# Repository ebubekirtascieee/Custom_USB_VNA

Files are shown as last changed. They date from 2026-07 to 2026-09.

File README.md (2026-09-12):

# Custom_USB_VNA
Single-port VNA (Vector Network Analyzer) operating in the 400 MHz – 3.0 GHz range, featuring a custom-designed 4-layer PCB based on the Raspberry Pi Pico 2 MCU and a USB interface.
Superior performance for 430 MHz (ISM), 900 MHz (ISM), 1090 MHz (ADS-B), 1.5 GHz (GPS), and 2.4 GHz (Wi-Fi/Bluetooth) metrology with minimal cost!



Pico_Top

Various types of charts support, including 1001 points Smith chart, via a Python-based (PyQt6) custom graphical user interface (GUI).

Test_GUI_2

Time Domain Reflectometry (TDR) for distance-to-fault calculations and automated cable loss measurements.

Cable_Loss

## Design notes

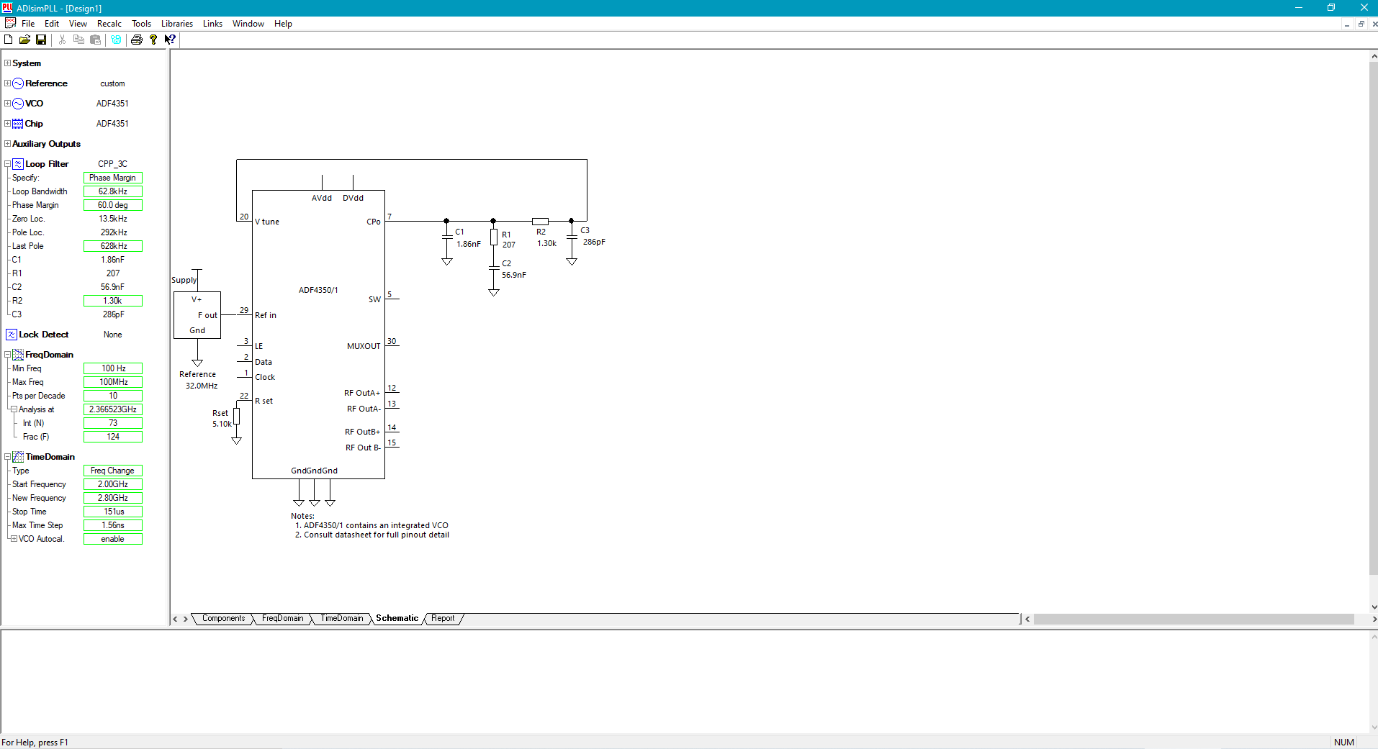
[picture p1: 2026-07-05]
Hardware/Loop_Filter.png

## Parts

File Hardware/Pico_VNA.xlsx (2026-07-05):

Comment | Description | Designator | Footprint | LibRef | Quantity
100nF 0603 | CAP 100nF 25V ±20% 0603 (1608 Metric) Thickness 1mm SMD | C1, C12, C13, C18, C21, C23, C24, C29, C30, C31, C35, C36, C41, C44, C51, C53, C56, C59, C61, C62, C75, C77, C79, C80, C81 | CAPC0603(1608)100_N | CMP-1035-02589-1 | 25
2.2uF 0805 | CAP CER 2.2UF 16V X7R 0805 | C2, C8, C10, C73 | FP-C0805C225K4RACAUTO-MFG | CMP-2007-03267-2 | 4
1uF 0805 |  | C3, C9, C11, C52, C57, C58, C74 | CAPC2013X145X50NL20T25 | CMP-2007-01121-1 | 7
0805 10nF |  | C4, C19 | CAPC2013X94X50ML20T25 | CMP-2007-04453-1 | 2
10uF 1206 | 10uF 16V ±10% 3Ω 1206 SMD Tantalum Capacitor TAJA106K016RNJ | C5, C6 | FP-TAJA-MFG | CMP-1661-00004-2 | 2
10nF 0603 | CAP 10nF 25V ±20% 0603 (1608 Metric) Thickness 1mm SMD | C7 | CAPC0603(1608)100_N | CMP-1035-02589-1 | 1
100pF 0603 |  | C14, C15, C20, C28, C40, C42, C43, C45, C48, C49, C55, C71, C72, C82, C83, C84 | CAPC1608X92X38LL15T08 | CMP-2006-01182-1 | 16
1.8nF 0603 | CAP CER 1800PF 25V X7R 0603 | C16, C32, C68, C70 | FP-C0603C-CF-MFG | CMP-03020-009150-1 | 4
270pF 0603 |  | C17, C33 | CAPC1608X92X38LL15T08 | CMP-2006-01334-1 | 2
10uF 1206 | CAP 10uF 16V ±5% 1206 (3216 Metric) Thickness 1.9mm SMD | C22, C25, C34, C37, C50, C54, C60, C63, C64, C65, C66, C67, C69 | CAPC1206(3216)190_M | CMP-1037-04973-1 | 13
100nF 0603 | CAP 100nF 16V ±0.1pF 0603 (1608 Metric) Thickness 1mm SMD | C26, C27, C38, C39, C76, C78 | CAPC0603(1608)100_L | CMP-1035-00228-1 | 6
56nF 0603 |  | C46, C47 | CAPC1608X90X35LL15T15 | CMP-2006-04522-1 | 2
PA2748NL | CHOKE COMMON MODE 1125UH 1.8A SMD | CMC1 | DFN838P1270X560-4N | PA2748NL | 1
PESD5V0S1BA,115 | TVS DIODE 5V 14V SOD323 | D2 | FP-SOD323-CA-MFG | CMP-14432-000001-1 | 1
150120VS75000 | Led, Green, 570 Nm, 2 V, 30 Ma, 40 Mcd Rohs Compliant: Yes | DS1 | WL-SMCW_1206_150120xx75000 | CMP-1426-00016-4 | 1
LCB3216-102Y-N | Chip Ferrite Bead, 1206, 1kΩ @ 100MHz, max. 0.200Ω, 25%, 2A | FB1, FB2, FB3, FB4, FB5, FB8 | FP-BLM31-0_2-t1_6-IPC_C | CMP-06046-002145-1 | 6
BLM18HE152SN1D | Chip Ferrite Bead, 0603, 1500Ω @ 100MHz, 0.5Ω, 25%, 500mA | FB6, FB7 | FP-BLM18-0_15-t0_8-IPC_C | CMP-0686-00368-3 | 2
BMI-S-205-F | RF Shield Frame 1.000 _25.40mm_ X 1.500 _38.10mm_ Solder | H1, H2, H3 | LAIRD_BMI-S-205-F | CMP-058-000000-1 | 3
32K201-400L5 | CONN SMA JACK R/A 50OHM PCB | J1 | FP-32K201-400L5-MFG | CMP-0751-00005-2 | 1
USB4125-GF-A_REVA2 |  | J2 | GCT_USB4125-GF-A_REVA2 | CMP-039-000000-1 | 1
5-146256-2 | CONN HEADER VERT 4POS 2.54MM | J3 | FP-5-146256-2-MFG | CMP-03369-000128-1 | 1
U.FL-R-SMT-1(80) | CONN U.FL RCPT STR 50 OHM SMD | J4, J5 | FP-U_FL-R-SMT-1_80-MFG | CMP-11598-000004-1 | 2
5.6nH 0603 |  | L1, L2, L3, L4 | FP-AISC-0603HP-MFG | CMP-27750-000002-1 | 4
18nH 0805 | 18 nH Unshielded Drum Core, Wirewound Inductor 800 mA 130mOhm 0805 (2012 Metric) 0805CT-180EGTS | L5, L6, L7 | FP-LQW2BAN_00-MFG | CMP-06042-010439-1 | 3
5.1k 0603 | RES SMD 100 OHM 1% 1/8W 0603 | R1, R2 | FP-MCT0603-IPC_B | CMP-02407-010205-1 | 2
1Meg 0603 | RES SMD 1 MEGA OHM 1% 1/8W 0603 | R3 | FP-MCT0603-IPC_B | CMP-02407-010205-1 | 1
33R 0603 | RES 33 OHM 1% 1/4W 0603 | R4, R15 | FP-SR0603-MFG | CMP-03412-011068-1 | 2
4.7k 0603 | RES SMD 4.7kΩ 0.1% 1/16W 0603 | R5, R14, R42, R43, R46, R47 | FP-CPF0603-MFG | CMP-03211-011109-1 | 6
33R 0603 | RES SMD 33Ω 0.1% 1/16W 0603 | R6, R8, R10, R19, R32, R33, R54, R55, R57, R58, R59, R60, R61, R62, R63, R65, R66, R67, R68, R69, R70, R71, R73, R74 | FP-CPF0603-MFG | CMP-03211-006902-1 | 24
49.9R 0603 | RES SMD 49.9 OHM 1% 1/10W 0603 | R7, R12, R30, R31, R35, R37 | FP-RT0603-MFG | CMP-03412-022019-1 | 6
210R 0603 | RES 210Ω 1.00% 0.1W 0603 | R11, R18, R36 | FP-AC0603-IPC_B | CMP-03412-003885-2 | 3
0R 0603 | RES 0 OHM JUMPER 1/4W 0603 | R20, R24, R38 | FP-HCJ0603-MFG | CMP-26527-000122-1 | 3
16.5R 0603 | RES SMD 16.5 OHM 1% 1/10W 0603 | R21, R22, R23 | FP-RT0603-MFG | CMP-03412-005655-1 | 3
37.4R 0603 | RES SMD 37.4 OHM 0.1% 1/10W 0603 | R25 | FP-RT0603-MFG | CMP-03412-012358-1 | 1
150R 0603 | RES 150 OHM 1/10W .1% SMD 0603 | R26, R27 | FP-RT0603-MFG | CMP-2000-04520-2 | 2
1.3k 0603 | RES Thin Film, 1.3kΩ, 0.1%, 0.1W, 25ppm/°C, 0603 | R28, R29 | FP-TFCR0603-IPC_B | CMP-250906-187165-1 | 2
10k 0603 | RES SMD 10K OHM 0.05% 1/10W 0603 | R34, R39 | FP-RT0603-MFG | CMP-03412-024743-1 | 2
100k 0603 | RT0603 100KΩ 0.1W 50 ppm/°C 1.00% | R40, R41 | FP-RT0603-MFG | CMP-03412-006967-1 | 2
1k 0603 | RES Thin Film, 1kΩ, 0.1%, 0.1W, 25ppm/°C, 0603 | R44, R45, R48, R49, R52, R53 | FP-TFCR0603-MFG | CMP-250906-149963-1 | 6
100R 0603 | RES SMD 100 OHM 1% 1/8W 0603 | R50, R51 | FP-MCT0603-MFG | CMP-02407-008087-1 | 2
HHM22137A2 | RF Directional Coupler General Purpose 0603 (1608 Metric), 6 PC Pad | T1, T2 | HHM22137A2 | CMP-012-00000-1 | 2
RASPBERRY_PI_PICO_2 | Raspberry Pi Board, Arm Cortex-M0+; Core Architecture:Arm; Core Sub-Architecture:Cortex-M0+; Kit Contents:Raspberry Pi Pico Board; No. Of Bits:32Bit; Silicon Core Number:Rp2040; Silicon Manufacturer:Raspberry Pi | U1 | RASPBERRY_PI_PICO | CMP-007-000000-1 | 1
TPS7A2033PDBVR | IC REG LINEAR 3.3V 300MA SOT23-5 | U2, U3, U4, U16 | FP-DBV0005A-MFG | CMP-04917-000300-1 | 4
ADF4351BCPZ | Wideband Synthesizer with Integrated VCO, CP-32-2, Pb-Free, 490 Tray | U5, U6 | ADI-CP-32-2_N | CMP-0287-00014-1 | 2
GVA-62+ | No Description Available | U7, U8, U15 | DF782_MNC | GVA-63+ | 3
SYM-63LH+ | RF Mixer IC Cellular, GPS, ISM, PCS, WCDMA 1MHz ~ 6GHz | U9, U10 | FP-SYM-30DMHW+-MFG | CMP-199893-000002-1 | 2
PCM1808PWR | 24-bit, 99-dB SNR, 96-kHz stereo ADC with single-ended inputs | U11 | SOP65P640X120-14N | CMP-052-000000-1 | 1
TPS7A2045PDBVR |  | U12 | SOT95P280X145-5N | CMP-056-000000-1 | 1
OPA2365AIDR | IC OPAMP GP 2 CIRCUIT 8SOIC | U13, U14 | FP-D0008A-MFG | CMP-0272-00746-4 | 2
SI8641BB-B-IS1 | General Purpose Digital Isolator 2500Vrms 4 Channel 150Mbps 35kV/Âµs CMTI 16-SOIC (0.154, 3.90mm Width) | U17, U18, U19 | SOIC127P600X265-16N | CMP-060-000000-1 | 3
ECS-TXO-3225MV-320-TR | TCXO Oscillators 32.000 MHZ Multi-Volt +1.7 3.6V HCMOS TCXO +/-2.5 ppm -30 +85 C 3.2x 2.5mm RoHS | Y1 | OSC_ECS-TXO-3225MV-320-TR | CMP-041-000000-1 | 1

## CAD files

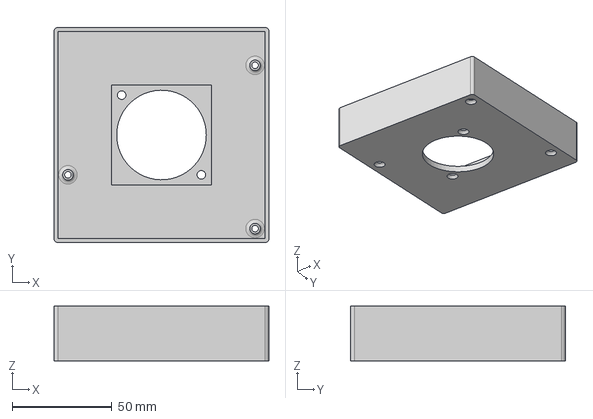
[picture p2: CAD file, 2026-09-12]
Mechanic/VNA_Box_Bottom.step
108.0 x 108.0 x 27.6 mm

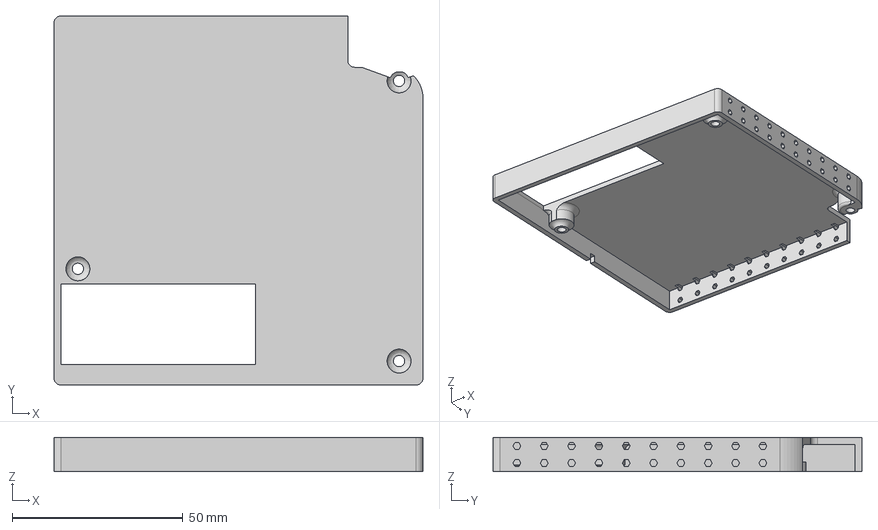
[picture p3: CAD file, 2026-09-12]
Mechanic/VNA_Box_Top.step
108.0 x 108.0 x 10.0 mm

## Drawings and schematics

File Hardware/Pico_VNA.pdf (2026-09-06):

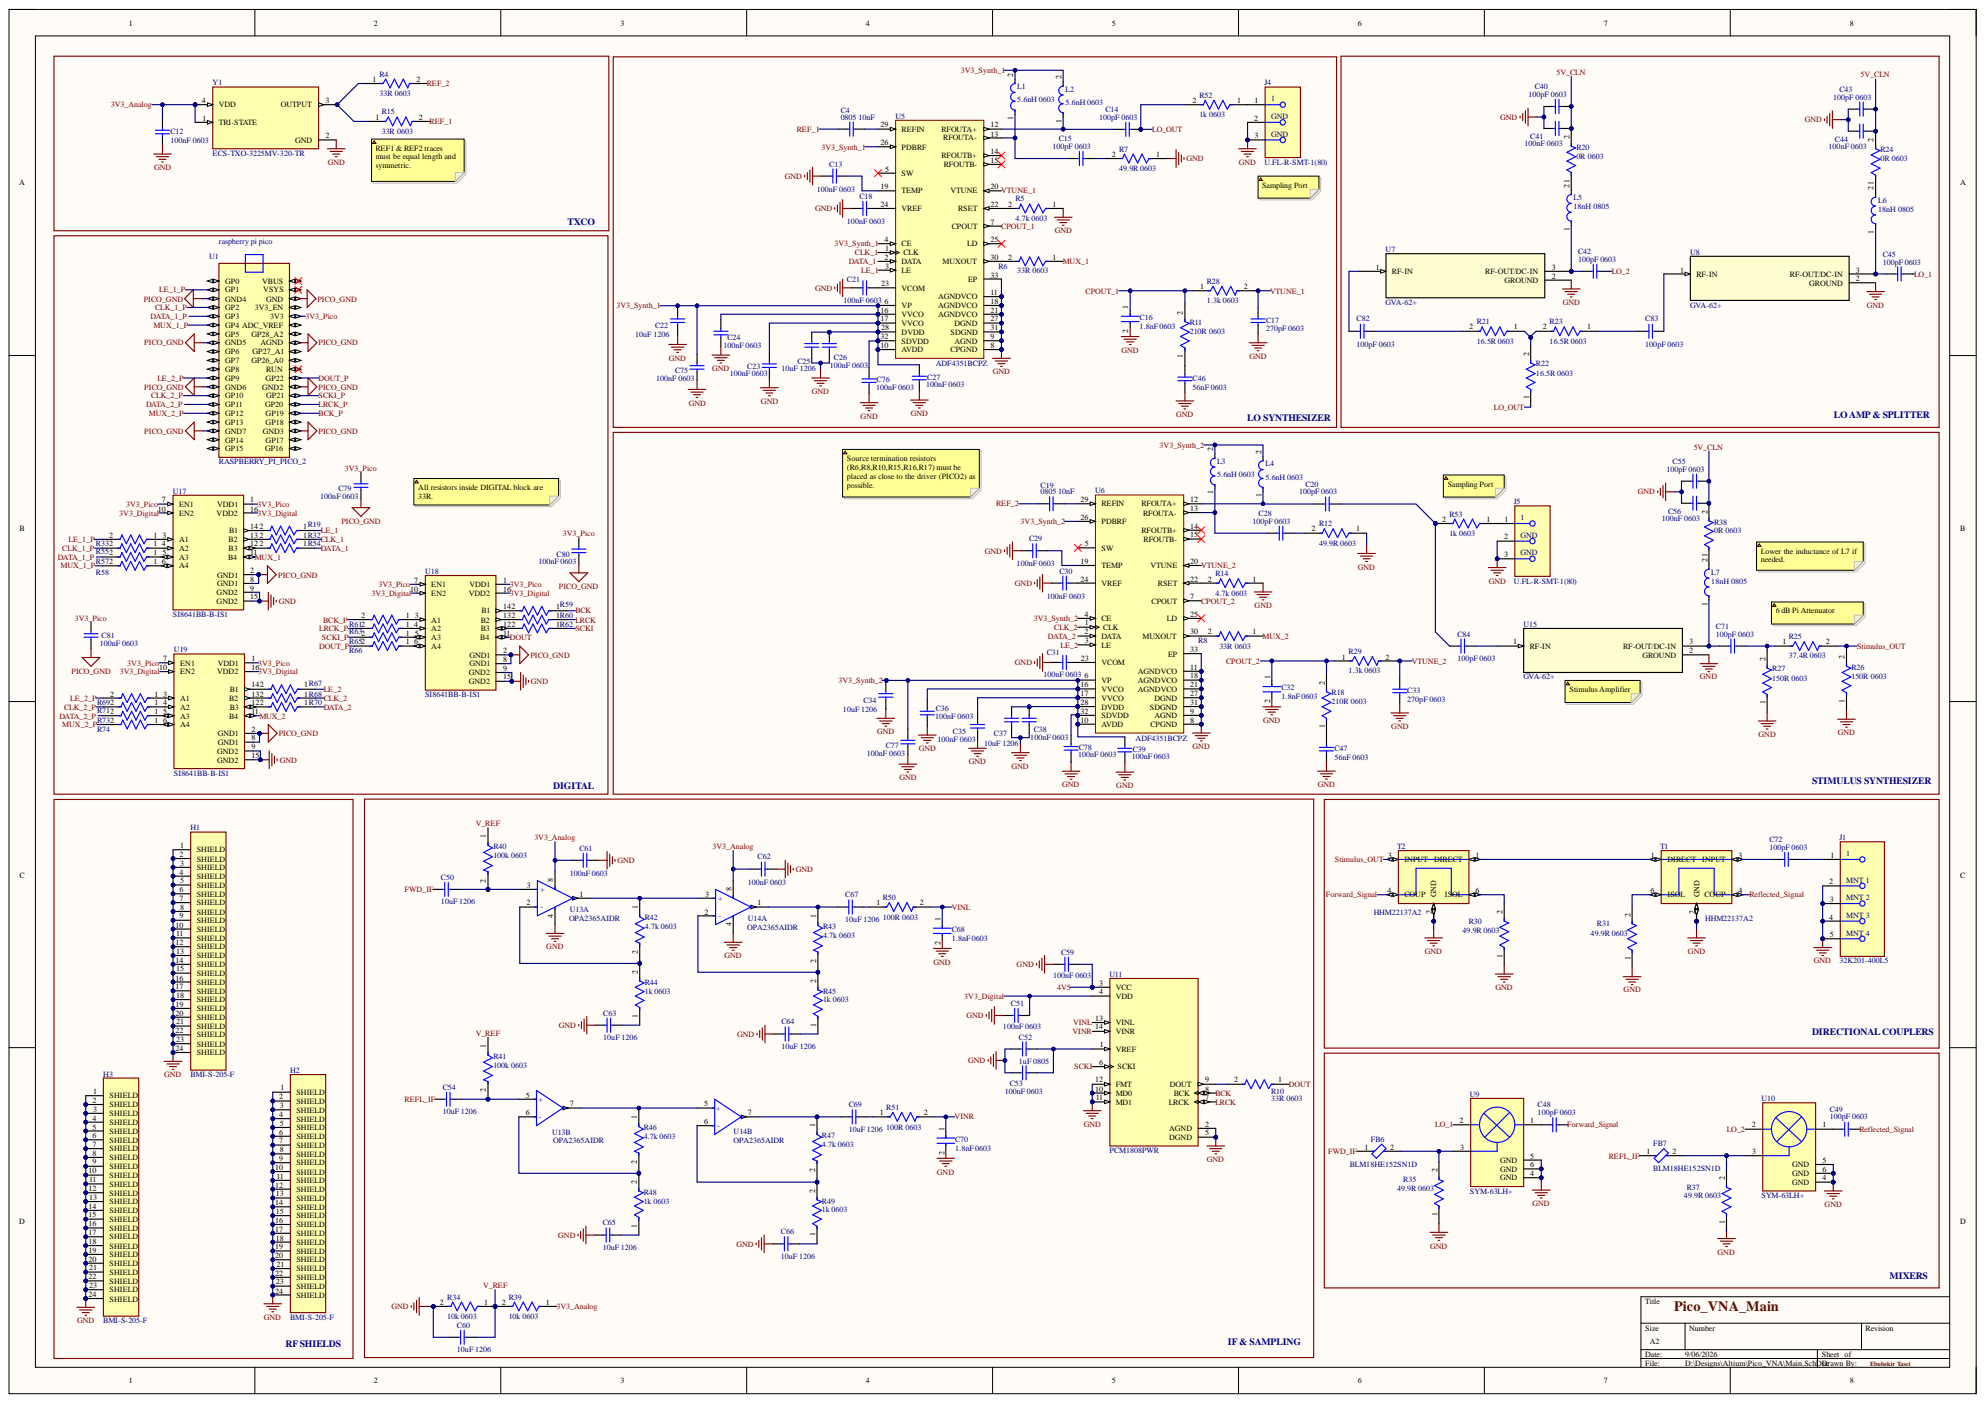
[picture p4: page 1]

REF1 & REF2 traces
must be equal length and
symmetric.

Source termination resistors
(R6,R8,R10,R15,R16,R17) must be
placed as close to the driver (PICO2) as
possible.

All resistors inside DIGITAL block are

Lower the inductance of L7 if
needed.

STIMULUS SYNTHESIZER

H1 | V_REF | J1

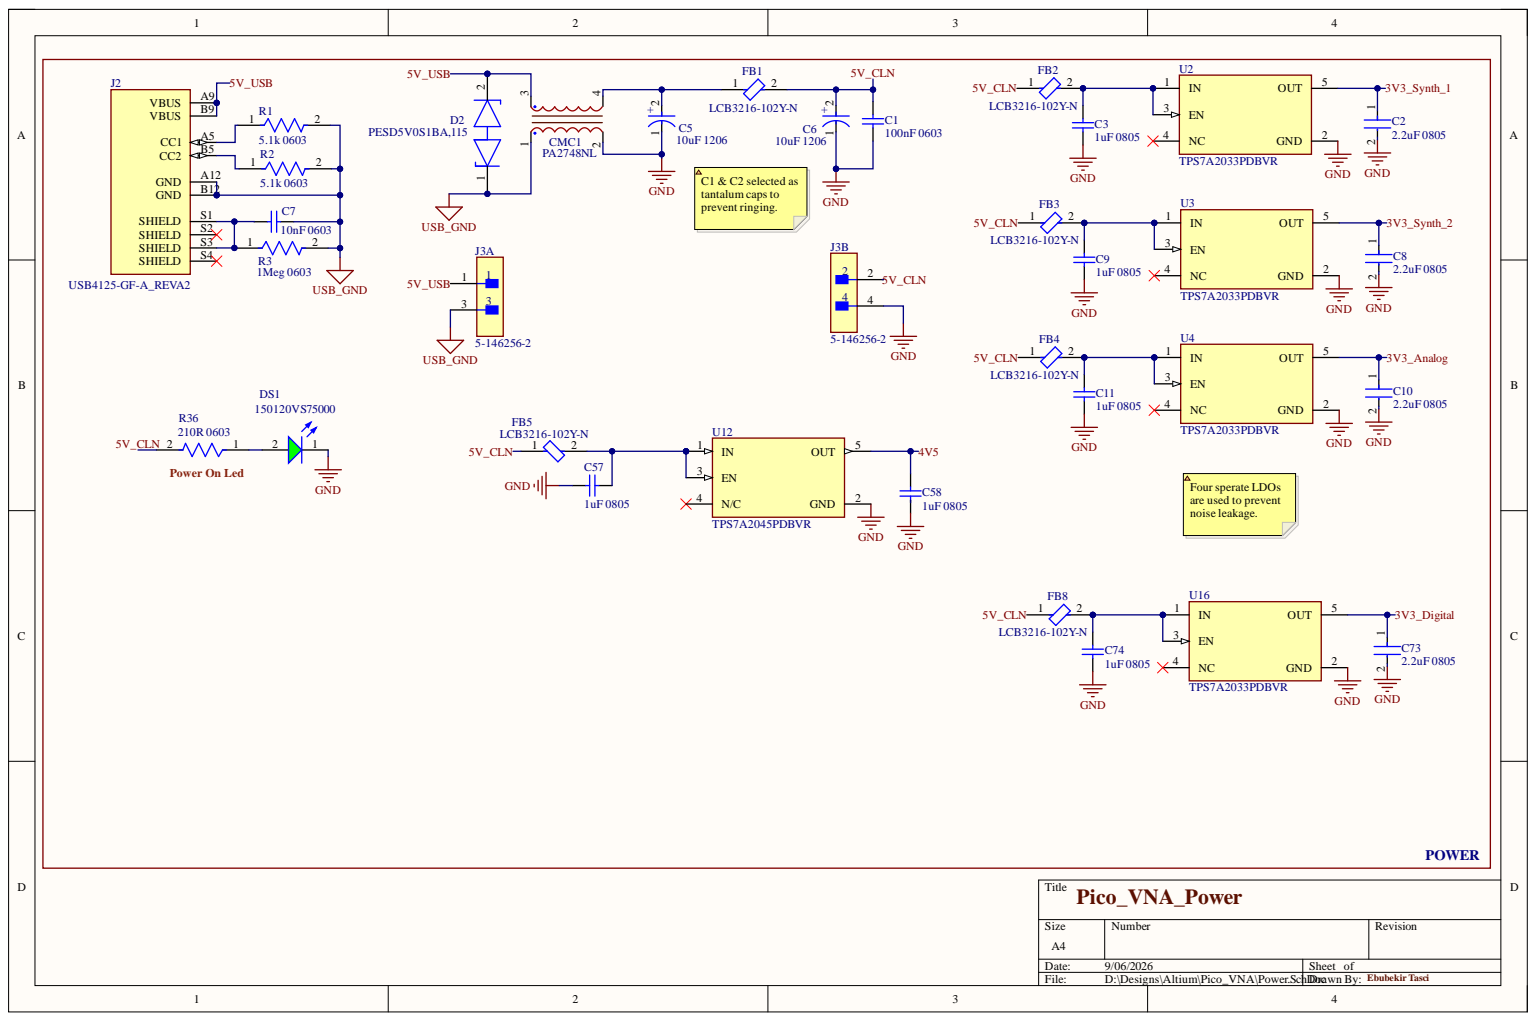
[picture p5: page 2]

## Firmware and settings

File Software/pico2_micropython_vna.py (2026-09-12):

import sys
import struct
import uselect
from machine import Pin, SPI, I2S, PWM, freq
import time

# Set CPU to exactly 144 MHz
freq(144_000_000) 

class ADF4351:
    def __init__(self, spi, cs_pin, ref_clk=32.0):
        self.spi = spi
        self.cs = Pin(cs_pin, Pin.OUT)
        self.cs.value(1)
        self.ref_clk = ref_clk
        
    def write_reg(self, reg):
        buf = bytearray(4)
        buf[0], buf[1], buf[2], buf[3] = (reg >> 24) & 0xFF, (reg >> 16) & 0xFF, (reg >> 8) & 0xFF, reg & 0xFF
        self.cs.value(0)
        self.spi.write(buf)
        self.cs.value(1)
        
    def init_registers(self):
        self.write_reg(0x00580005) 
        self.write_reg(0x0000000B) 
        self.write_reg(0x18004E42) 

    def set_frequency(self, freq_mhz, power_level=3):
        vco = float(freq_mhz)
        div_bits = 0
        while vco < 2200.0 and div_bits < 7:
            vco *= 2
            div_bits += 1
            
        MOD = 4000
        n_total = vco / self.ref_clk
        INT, FRAC = int(n_total), int(round((n_total - int(n_total)) * MOD))
        bscc = 255 
        
        self.write_reg((1 << 23) | (div_bits << 20) | (bscc << 12) | (1 << 5) | (power_level << 3) | 4)
        self.write_reg((1 << 15) | (MOD << 3) | 1)
        self.write_reg((INT << 15) | (FRAC << 3) | 0)

# Synthesizer Setup
spi_lo = SPI(0, baudrate=1_000_000, polarity=0, phase=0, sck=Pin(2), mosi=Pin(3))
synth_lo = ADF4351(spi_lo, cs_pin=1)
spi_rf = SPI(1, baudrate=1_000_000, polarity=0, phase=0, sck=Pin(10), mosi=Pin(11))
synth_rf = ADF4351(spi_rf, cs_pin=9)

synth_lo.init_registers()
synth_rf.init_registers()

# Hardware Lock Detect Pins
lock_lo = Pin(4, Pin.IN, Pin.PULL_DOWN)
lock_rf = Pin(12, Pin.IN, Pin.PULL_DOWN)

# Master Clock Generation
scki = PWM(Pin(21))
scki.freq(24000000) 
scki.duty_u16(32768) 

# I2S DMA Setup
audio = I2S(0, sck=Pin(19), ws=Pin(20), sd=Pin(22), 
            mode=I2S.RX, bits=32, format=I2S.STEREO, rate=93750, ibuf=8192)
i2s_buf = bytearray(2048) 

poller = uselect.poll()
poller.register(sys.stdin, uselect.POLLIN)
IF_OFFSET_MHZ = 0.024 

try:
    while True:
        if poller.poll(0):
            cmd = sys.stdin.buffer.read(1)
            
            if cmd == b'F': 
                freq_bytes = bytearray()
                
                while len(freq_bytes) < 4:
                    chunk = sys.stdin.buffer.read(4 - len(freq_bytes))
                    if chunk:
                        freq_bytes.extend(chunk)
                    else:
                        time.sleep(0.001)
                
                if len(freq_bytes) == 4:
                    freq_lo = struct.unpack('<f', freq_bytes)[0]
                    freq_rf = freq_lo + IF_OFFSET_MHZ
                    
                    synth_lo.set_frequency(freq_lo, power_level=3)
                    synth_rf.set_frequency(freq_rf, power_level=2)
                    
                    # 1. Active Digital Lock Polling
                    # Actively drain the buffer so it does not fill up while waiting for the silicon to assert the lock pins.
                    t_start = time.ticks_ms()
                    while lock_lo.value() == 0 or lock_rf.value() == 0:
                        audio.readinto(i2s_buf)
                        if time.ticks_diff(time.ticks_ms(), t_start) > 50:
                            break
                    
                    # 2. Active Analog Settling Delay
                    # Each readinto() blocks for exactly 2.73ms. Looping 10 times yields a perfect 27.3ms delay.
                    # The I2S hardware buffer remains completely empty the entire time.
                    for _ in range(10):
                        audio.readinto(i2s_buf) 
                    
                    # 3. Final Capture
                    # Read the pristine, aligned, steady-state sine wave.
                    audio.readinto(i2s_buf) 
                    
                    sys.stdout.buffer.write(b'VNA1')
                    sys.stdout.buffer.write(struct.pack('<f', freq_lo))
                    sys.stdout.buffer.write(i2s_buf)

except KeyboardInterrupt:
    audio.deinit()

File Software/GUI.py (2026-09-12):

import sys
import struct
import time
import numpy as np
import pyqtgraph as pg
import pyqtgraph.exporters
import serial
import serial.tools.list_ports
from scipy.signal import butter, filtfilt, resample, medfilt, find_peaks, get_window
from PyQt6.QtWidgets import (QApplication, QMainWindow, QVBoxLayout, QHBoxLayout,
                             QWidget, QPushButton, QLabel, QDoubleSpinBox, QGroupBox,
                             QComboBox, QMessageBox, QFileDialog, QLineEdit, QTableWidget,
                             QTableWidgetItem, QHeaderView, QTabWidget)
from PyQt6.QtCore import QTimer, Qt


def interp_complex(x_new, x_old, y_complex):
    real_interp = np.interp(x_new, x_old, np.real(y_complex))
    imag_interp = np.interp(x_new, x_old, np.imag(y_complex))
    return real_interp + 1j * imag_interp


class VNAMaster(QMainWindow):
    def __init__(self):
        super().__init__()
        self.setWindowTitle("VNA Metrology Engine: S11, TDR & Time-Domain Gating")
        self.resize(1600, 950)
        self.port = None
        self.rx_buffer = bytearray()

        self.is_sweeping = False
        self.sweep_mode = 'IDLE'
        self.sweep_idx = 0
        self.sweep_points = 1001
        self.sweep_start_time = 0.0

        self.freq_array = np.zeros(self.sweep_points)
        self.active_E_D = np.zeros(self.sweep_points, dtype=complex)
        self.active_E_S = np.zeros(self.sweep_points, dtype=complex)
        self.active_E_T = np.zeros(self.sweep_points, dtype=complex)

        self.raw_mag_data = np.full(self.sweep_points, np.nan)
        self.raw_phase_data = np.full(self.sweep_points, np.nan)
        self.plot_mag_data = np.full(self.sweep_points, np.nan)
        self.plot_phase_data = np.full(self.sweep_points, np.nan)

        self.cal_status = {'OPEN': False, 'SHORT': False, 'LOAD': False}
        self.is_calibrated = False
        self.cal_freq_array = None
        self.base_E_D = None
        self.base_E_S = None
        self.base_E_T = None

        self.markers = []
        self.tdr_markers = []
        self.tdr_d_array = np.array([])
        self.tdr_mag_array = np.array([])

        central_widget = QWidget()
        layout = QVBoxLayout(central_widget)
        self.setCentralWidget(central_widget)

        # --- ROW 1: Connection & Export ---
        top_row = QHBoxLayout()
        conn_group = QGroupBox("Hardware Connection")
        conn_layout = QHBoxLayout()
        self.combo_com = QComboBox()
        self.refresh_ports()
        self.btn_refresh = QPushButton("↻")
        self.btn_refresh.setMaximumWidth(40)
        self.btn_refresh.clicked.connect(self.refresh_ports)
        self.btn_connect = QPushButton("Connect")
        self.btn_connect.setCheckable(True)
        self.btn_connect.clicked.connect(self.toggle_connection)
        conn_layout.addWidget(QLabel("COM Port:"))
        conn_layout.addWidget(self.combo_com)
        conn_layout.addWidget(self.btn_refresh)
        conn_layout.addWidget(self.btn_connect)
        conn_group.setLayout(conn_layout)
        top_row.addWidget(conn_group)

        export_group = QGroupBox("Export Data & Graphics")
        export_layout = QHBoxLayout()
        self.input_img_name = QLineEdit()
        self.input_img_name.setPlaceholderText("VNA_Export")

        self.btn_export_png = QPushButton("Save PNG")
        self.btn_export_png.clicked.connect(self.export_png)

        self.btn_export_s1p = QPushButton("Save CST (.s1p)")
        self.btn_export_s1p.clicked.connect(self.export_s1p)

        export_layout.addWidget(QLabel("Filename:"))
        export_layout.addWidget(self.input_img_name)
        export_layout.addWidget(self.btn_export_png)
        export_layout.addWidget(self.btn_export_s1p)
        export_group.setLayout(export_layout)
        top_row.addWidget(export_group)
        layout.addLayout(top_row)

        # --- ROW 2: Sweep & Calibration ---
        mid_row = QHBoxLayout()
        control_group = QGroupBox("Sweep Configuration")
        control_layout = QHBoxLayout()
        self.spin_start = QDoubleSpinBox()
        self.spin_start.setRange(50.0, 4400.0)
        self.spin_start.setValue(400.0)
        self.spin_stop = QDoubleSpinBox()
        self.spin_stop.setRange(50.0, 4400.0)
        self.spin_stop.setValue(3000.0)
        self.combo_pts = QComboBox()
        self.combo_pts.addItems(["101", "201", "501", "1001"])
        self.combo_pts.setCurrentText("1001")
        self.combo_filter = QComboBox()
        self.combo_filter.addItems(["Off", "3 (Light)", "5 (Medium)", "11 (Aggressive)"])

        self.spin_ed = QDoubleSpinBox()
        self.spin_ed.setRange(-5000.0, 5000.0)
        self.spin_ed.setValue(0.0)
        self.spin_ed.setSuffix(" ps")
        self.spin_ed.setToolTip("Port Extension (One-way electrical delay)")

        self.btn_normal = QPushButton("Start Sweep")
        self.btn_normal.setStyleSheet("background-color: #005577; color: white;")
        self.btn_normal.clicked.connect(lambda: self.start_sweep('NORMAL'))
        self.btn_stop = QPushButton("STOP")
        self.btn_stop.setStyleSheet("background-color: #880000; color: white;")
        self.btn_stop.clicked.connect(self.stop_sweep)
        self.btn_toggle_adc = QPushButton("Hide ADC")
        self.btn_toggle_adc.setCheckable(True)
        self.btn_toggle_adc.clicked.connect(self.toggle_adc)

        control_layout.addWidget(QLabel("Start:"))
        control_layout.addWidget(self.spin_start)
        control_layout.addWidget(QLabel("Stop:"))
        control_layout.addWidget(self.spin_stop)
        control_layout.addWidget(QLabel("Pts:"))
        control_layout.addWidget(self.combo_pts)
        control_layout.addWidget(QLabel("Filter:"))
        control_layout.addWidget(self.combo_filter)
        control_layout.addWidget(QLabel("Delay:"))
        control_layout.addWidget(self.spin_ed)
        control_layout.addWidget(self.btn_normal)
        control_layout.addWidget(self.btn_stop)
        control_layout.addWidget(self.btn_toggle_adc)
        control_group.setLayout(control_layout)
        mid_row.addWidget(control_group)
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

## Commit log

2026-09-12 Refactor Time-Domain Gating axis to absolute time (ns)
    Decoupled the Time-Domain Gating algorithm from the Velocity Factor (VF) multiplier.
    Transitioned the gating graph's X-axis from physical distance (meters) to absolute one-way time (nanoseconds).
    Physics Justification: A single VF is mathematically invalid for mixed-dielectric systems. Using absolute time prevents spatial distortion of the multipath echoes and ensures the Tukey window boundaries remain mathematically accurate before the Forward FFT reconstruction.
    Retained the VF-dependent physical distance (meters) scale strictly for the Distance-to-Fault and Cable Loss tabs, where single-medium coaxial analysis is assumed.
    [GUI.py]
2026-11-02 Update README with new images and benchmarks
    Added new images and benchmark results for Multi-Band Antenna Analysis.
2026-11-02 Clarify Multi-Band Antenna Analysis benchmark results
    Updated benchmark results description for clarity and accuracy.
